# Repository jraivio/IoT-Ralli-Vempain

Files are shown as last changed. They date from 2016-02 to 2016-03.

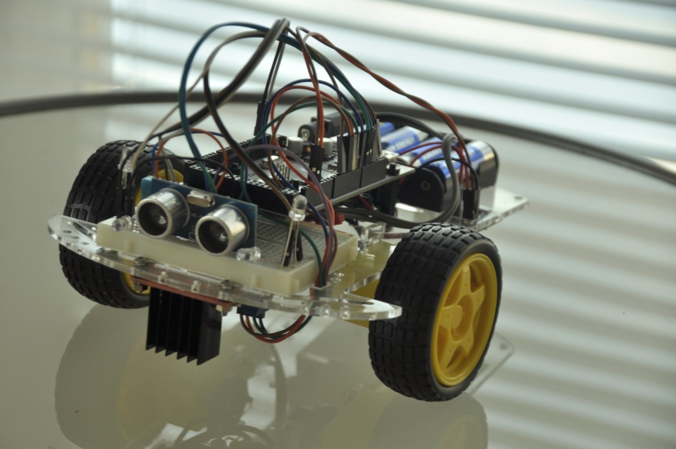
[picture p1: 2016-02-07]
Hardware/Pictures/_DSC5885.JPG

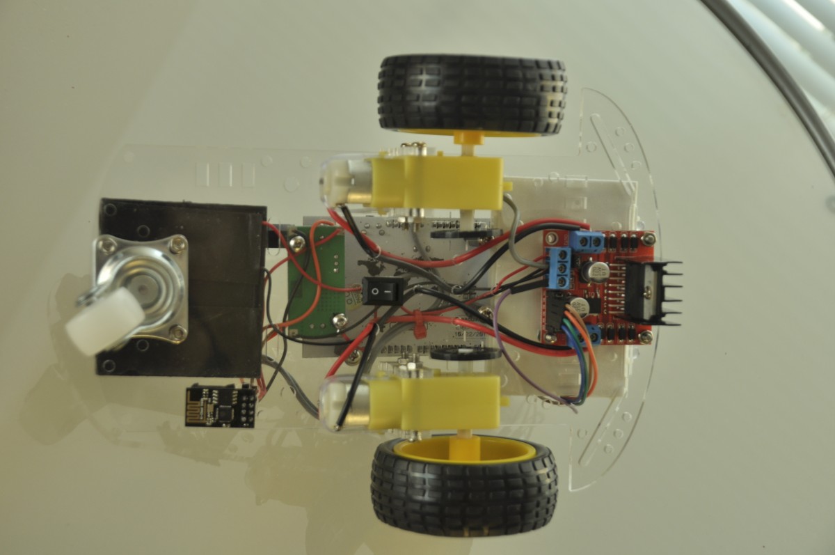
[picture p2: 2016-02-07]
Hardware/Pictures/_DSC5898.JPG

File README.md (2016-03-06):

# IoT-Ralli-Vempain
![alt tag] (https://github.com/jraivio/IoT-Ralli-Vempain/blob/master/Hardware/Pictures/Cloudyralli_mid.png) ![alt tag] (https://github.com/jraivio/IoT-Ralli-Vempain/blob/master/Hardware/Pictures/_DSC5885_small.JPG)

###Description of project:
This project aims to develop [Internet of Things (IoT)] (https://en.wikipedia.org/wiki/Internet_of_Things) specific development environment for educational institutions. Easy availability and low cost components are the design principles of this gadget. In addition, an important factor is the availability of the source code for hardware drivers. This project is focusing to produce a prototype device with required IoT features and interfaces. The brains to control a robot can be placed in the cloud server, if necessary.
Source code type of approach is mandatory. All used 3rd party libraries in this repository are also available from the github repositories as well. Including selected hardware e.g [Arduino] (https://www.arduino.cc) and [esp8266] (http://www.esp8266.com) both are based on the model of [open source electronics] (http://www.open-electronics.org/).  

###Content of Ralli-Vempain repository:     
- [Arduino Code - Refence functions to control the gadget] (https://github.com/jraivio/IoT-Ralli-Vempain/tree/master/ArduinoCode)    
- [Interface descriptions - Reference implementation to communicate with the gadget] (https://github.com/jraivio/IoT-Ralli-Vempain/wiki)  
- [Wiring and HW layouts - Instructions to install the gadget] (https://github.com/jraivio/IoT-Ralli-Vempain/tree/master/Hardware)  

###Getting started with development environment:        
- [Getting started with Arduino: Arduino development board pinouts, IDE setup, Arduino SW libraries, sample code, etc] (https://www.arduino.cc/en/Guide/HomePage)   
- [Getting started with esp8266: Basics, pinouts and flashing instruction, etc] (http://www.esp8266.com/wiki/doku.php?id=getting-started-with-the-esp8266)    
- [Open Electronics is the brainchild of a world leader in hobby electronics] (http://www.open-electronics.org)   
- [Arduino Course for Absolute Beginners] (https://www.youtube.com/watch?v=09zfRaLEasY)    
- [ESP8266 - Getting Started & Connected] (https://www.youtube.com/watch?v=z07zjfOHb8E)    
- [This project is using 3rd party libraries. The library bundle can be copied here to your local ...'Arduino/libraries' folder as such or alternatively you could download the latest versions from the original github location.] (https://github.com/jraivio/IoT-Ralli-Vempain/tree/master/ArduinoCode/libraries)

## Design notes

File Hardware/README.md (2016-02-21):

###Eye Candy: Ralli-Vempain droid equipped with all bells and whistles

![alt tag] (https://github.com/jraivio/IoT-Ralli-Vempain/blob/master/Hardware/Pictures/Ralli-Vempain-layout.jpg)

_Note that layout description is overal. Some late findings... 6V battery is not enough. 7V-12V is recommended._    
_Not up-to-dated picture. Large number of sensors are missing_     

###IOT Droid wiring diagram by Fritzing tool:
![alt tag] (https://github.com/jraivio/IoT-Ralli-Vempain/blob/master/Hardware/Pictures/Ralli-Vempain-Fritzing-wiring.png)
_Note that layout description is overal. L298N requires additional control pinouts. L298N enA-> Arduino pin8 and L298N enB-> Arduino pin3._    

Wiring diagram is designed by [Fritzing tool.](http://fritzing.org/home/) The source code of the above wiring diagram is available also in this [IOT-Ralli-Vempain repository](https://github.com/jraivio/IoT-Ralli-Vempain/blob/master/Hardware/Rally_Droid2.fzz)

###List of selected hardware:
- [Microcontroller: Arduino Mega2560] (https://www.arduino.cc/en/Main/ArduinoBoardMega2560)
- [H-Bridge motor driver: L298N] (http://www.geeetech.com/wiki/index.php/L298N_Motor_Driver_Board)
- [Distance sensor: HC-SR04] (http://www.electroschematics.com/8902/hc-sr04-datasheet/)
- [Temperature and Humidity sensor: DHT11] (http://www.micropik.com/PDF/dht11.pdf)
- [RFID reader/writer: Mifare 13.56Mhz RC522] (http://www.nxp.com/documents/data_sheet/MFRC522.pdf)
- [Infrared line track Sensor: TCRT5000] (http://www.aliexpress.com/item/Sensor-For-Arduino-LM393-IR-Infrared-Line-Tracking-Transducer-TCRT5000-Obstacle-Avoidance-Module-Board-Photoelectric-Switch/3259121781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)
- [IOT Wifi-serial bridge: ESP8266-01] (https://www.adafruit.com/images/product-files/2471/0A-ESP8266__Datasheet__EN_v4.3.pdf)
- [Frame, Wheels and DC motor] (http://www.aliexpress.com/item/New-Motor-Smart-Robot-Car-Chassis-Kit-Speed-Encoder-Battery-Box-For-Arduino-Free-Shipping/1924502066.html)
- [Battery 2 x 3.7V: 18650] (https://www.reddit.com/r/flashlight/wiki/18650)
- [400 Point Breadboard] (http://www.aliexpress.com/item/400-Tie-Point-Interlocking-Solderless-mini-Breadboard-Free-Shipping-Dropshipping/1248613686.html)
- [3.3v regulator: AMS1117] (http://www.aliexpress.com/item/1pc-DC-DC-AMS1117-1-2V-Step-Down-Voltage-Regulator-Adapter-Convertor-2P-Single-Row-Hot/32369895833.html)

###esp8266 - esp-link:    
![alt tag] (http://www.partco.biz/verkkokauppa/images/tuotekuvat/e/esp8266_esp-01_top-medium.jpg)

This demo setup is based on esp8266-01 Serial-Wifi bridge. The default AT based firmware of esp8266 has replaced by the esp-link version.

esp-link serial bridge description:    
https://github.com/jeelabs/esp-link#serial-bridge-and-connections-to-arduino-avr-arm-lpc-microcontrollers

esp-link firmware releases and flashing instructions for esp8266:     
https://github.com/jeelabs/esp-link#releases-downloads

###esp-link user interface:   
esp-link comes with very handy user interface. It is possible to configure and admistrate Wifi parameters, managing MQTT/REST parameters and also handling serial events from Arduino by the Web Browser. The UI allows to send and receive serial events. This feature makes life much easier in case of troubleshooting.    

esp-link web UI. example of μC Console:    
![alt tag] (https://github.com/jraivio/IoT-Ralli-Vempain/blob/master/Hardware/Pictures/esp-link.png)    

###esp8266-01 pinout:   
![alt tag] (http://www.partco.biz/verkkokauppa/images/tuotekuvat/e/esp8266_esp-01_pinout-large.jpg)

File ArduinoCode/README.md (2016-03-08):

###High level SW architecture:
![alt tag] (https://github.com/jraivio/IoT-Ralli-Vempain/blob/master/Hardware/Pictures/Ralli_Vempain_highlevel_SW_arc.png)

[Arduino sample code for Ralli-Vempain gadget] (https://github.com/jraivio/IoT-Ralli-Vempain/blob/master/ArduinoCode/Ralli_Vempain_arduinoMega2560.ino)

**Getting started with Arduino SW development environment:**    
- [Download IDE] (https://www.arduino.cc/en/Main/Software)    
- [Instructions] (https://www.arduino.cc/en/Guide/Environment)     

**Following 3rd party libraries in use:**   
- [Temperature & Humidity sensor DHT11, Adafruit version] (https://github.com/adafruit/DHT-sensor-library)     
- [JSON string parser, by Benoit Blanchon] (https://github.com/bblanchon/ArduinoJson)    
- [RFID Card reader MFRC522, by Miguel Balboa] (https://github.com/miguelbalboa/rfid)    
- [Ultrasonic HC-SR04 library for Arduino by J.Rodrigo] (https://github.com/JRodrigoTech/Ultrasonic-HC-SR04)    
- [RTC DS1307 library by Adafruit] (https://github.com/adafruit/RTClib)    
- [Gyroscope + accelerometer MPU-6050 library for Arduino by Jeff Rowberg] (https://github.com/jrowberg/i2cdevlib)

[The library bundle can be copied to your local ...'Arduino/libraries' folder as such or alternatively you could download the latest versions from the original github location.] (https://github.com/jraivio/IoT-Ralli-Vempain/tree/master/ArduinoCode/libraries)     

**Following functions in use:**  
- `JsonReportSensorDHT()`: // DHT11 sensor data reader function & json report creation    
- `JsonReportSensorRFID()`: // RFID card sensor reader function & json report creation    
- `JsonReportSensorEdge()`: // Edge sensor reader function & json report creation    
- `JsonReportSensorDistance()`: // Ultrasonic distance sensor reader function & json report creation    
- `JsonReportSensorAccAndGyro()` : // Gyroscope + accelerometer reader function & json report creation    
- `driveMotor()`:  // Motor control functions, adapted for L298N    
- `serialEvent1()`: // Monitoring new serial events from esp  
- `HandleIncommingJson()`: // json parser for incoming commands from esp    
- `setup()`: // Standard Arduino function to setup the system    
- `loop()`: // Standard Arduino loop function. Primary function to call other functions.   

_Note that details of json string formats are described in the [wiki part] (https://github.com/jraivio/IoT-Ralli-Vempain/wiki)_

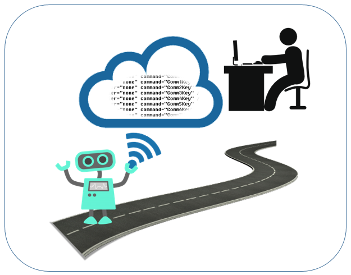
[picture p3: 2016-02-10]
Hardware/Pictures/Cloudyralli_mid.png

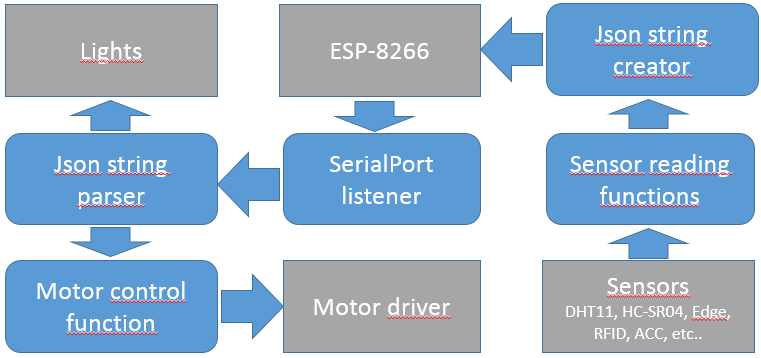
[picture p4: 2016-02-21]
Hardware/Pictures/Ralli_Vempain_highlevel_SW_arc.png

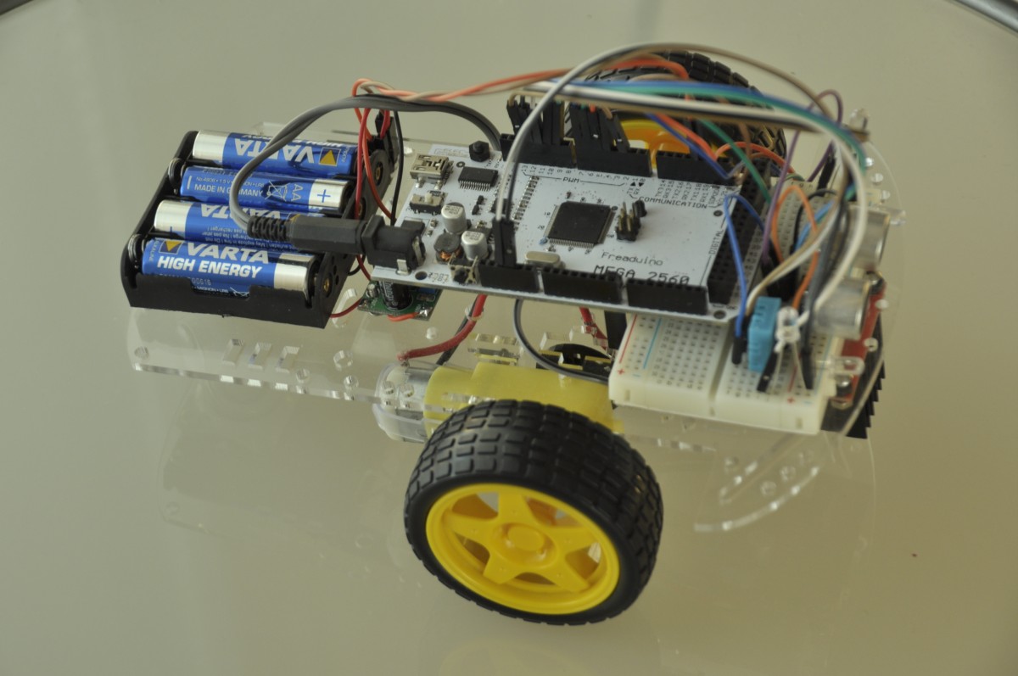
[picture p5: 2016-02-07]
Hardware/Pictures/_DSC5887.JPG

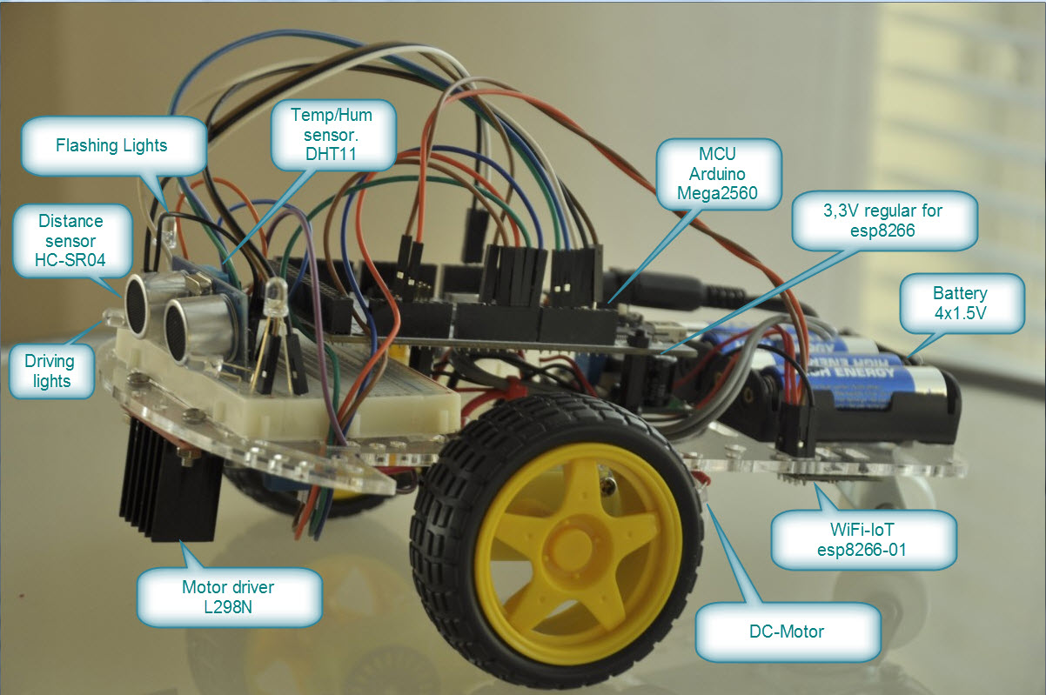
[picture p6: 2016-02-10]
Hardware/Pictures/Ralli-Vempain-layout.jpg

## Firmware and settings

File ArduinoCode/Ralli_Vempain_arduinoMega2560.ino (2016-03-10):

// IOT RalliDroid  
// Copyright Jukka Raivio and Jussi Salonen 2016
// MIT License
// 
// Example code is based on Arduino Mega2560 
//
// This arduino demo setup is connected to esp8266 Wifi via serial. 
// The http services are managed by esp-link firmware in ESP. The esp unit is working as Wifi-Serial bridge.
// No code changes are required for the esp-link
// Github repository for esp-link https://github.com/jeelabs/esp-link

// Temperature & Humidity sensor DHT11 lib & setup
// Adafruit version, https://github.com/adafruit/DHT-sensor-library
// Json description: https://github.com/jraivio/IoT-Ralli-Vempain/wiki
#include "DHT.h"
#define DHTPIN  2       // 2 digital pin 
#define DHTTYPE DHT11   
DHT dht(DHTPIN, DHTTYPE);

// I2C library
#include <Wire.h>
// RTC library by adafruit https://github.com/adafruit/RTClib
#include "RTClib.h"
RTC_DS1307 RTC;
String TimeStr ="";

// Multitasking functions by Arduino millis
// Initialization to enable multithreading features by using millis() functions  
// Sensor update interval
unsigned long previousMillis = 0;       // will store last time sensor updated
// the follow variables is a long because the time, measured in miliseconds,
// will quickly become a bigger number than can be stored in an int.
const long interval = 10000;            // Sensor data sending interval

// Json parser lib Copyright Benoit Blanchon 2014-2016, MIT License
// https://github.com/bblanchon/ArduinoJson
// Json description: https://github.com/jraivio/IoT-Ralli-Vempain/wiki
#include <ArduinoJson.h>
const char* command;
// Serial data handling, global variables
String inputString = "";         // a string to hold incoming data
boolean stringComplete = false;  // whether the string is complete
char inChar; // a char to handle incoming data

// RFID tag reader (NFC) MFRC522
/* ------------------------------------
  * RFID Card reader MFRC522 library by Miguel Balboa https://github.com/miguelbalboa/rfid
  * Signal      MFRC522      Mega 2560
  *             Pin          Pin       ´
  * -------------------------------------
  * RST/Reset   RST          49         
  * SPI SS      SDA(SS)      53       
  * SPI MOSI    MOSI         51        
  * SPI MISO    MISO         50        
  * SPI SCK     SCK          52        
*/
#include <SPI.h> // Arduino default SPI library
#include <MFRC522.h> 
#define RST_PIN   49     // Configurable, see typical pin layout above (valk)
#define SS_PIN    53    // Configurable, see typical pin layout above (vihr)
MFRC522 rfid(SS_PIN, RST_PIN); // Instance of the class
MFRC522::MIFARE_Key key; 
// Init array that will store new NUID 
byte nuidPICC[3];

/*
 * Gyroscope + accelerometer MPU-6050 library for Arduino by Jeff Rowberg
 * https://github.com/jrowberg/i2cdevlib
 * 
 */
#include <I2Cdev.h>
#include <MPU6050.h>

// Arduino Wire library is required if I2Cdev I2CDEV_ARDUINO_WIRE implementation
// is used in I2Cdev.h
#if I2CDEV_IMPLEMENTATION == I2CDEV_ARDUINO_WIRE
    #include "Wire.h"
#endif

// We use I2C address 0x69 as the default (0x68) is used by RTC
// Due to this AD0 pin must be pulled high
MPU6050 accelgyro(0x69);

// Global variables to store the values
int16_t ax, ay, az;
int16_t gx, gy, gz;

// Ultrasonic HC-SR04 library for Arduino by J.Rodrigo https://github.com/JRodrigoTech/Ultrasonic-HC-SR04
// Json description: https://github.com/jraivio/IoT-Ralli-Vempain/wiki
// Max distance 51 cm
#include <Ultrasonic.h>
#define TRIG_PIN 10     // Configurable Arduino pins for HC-SR04 Trig PIN
#define ECHO_PIN 9  // Configurable Arduino pins for HC-SR04 Echo pins
Ultrasonic ultrasonic(TRIG_PIN,ECHO_PIN); 

// Edge sensor pinouts
#define right_edge 23 // Right sensor
#define left_edge 22 // Left sensor

// Motor driver Setup
// Pins L298N -> Mega board
int enA = 8;
int in1 = 4;
int in2 = 5;
int in3 = 6;
int in4 = 7;
int enB = 3;
boolean motor_active = false;
// for motor delay
unsigned long mStartMillis = 0;      // will store last time motor delay update
int course; // direction
int mspeed; // motor speed
int mdelay; // motor delay
// millis for sensor reading interval while moving, delay 500 ms
boolean sensor_moving = false;
int sensor_moving_reports = 500;
unsigned long sensor_moving_previousMillis = 0;      // will store last time light delay update
// light blinking 
boolean pin13_blinking = false;
boolean pin12_blinking = false;
boolean pin11_blinking = false;
int pin13_delay;
int pin12_delay;
int pin11_delay;
unsigned long pin13_previousMillis = 0;      // will store last time light delay update
unsigned long pin12_previousMillis = 0;      // will store last time light delay update
unsigned long pin11_previousMillis = 0;      // will store last time light delay update

void JsonReportSensorDHT() {
 
  // DHT functions
  // Reading temperature or humidity takes about 250 milliseconds!
  float h = dht.readHumidity();  float t = dht.readTemperature();
  // Read temperature as Fahrenheit (isFahrenheit = true)
    float f = dht.readTemperature(true);
    // Compute heat index in Fahrenheit (the default)
    float hif = dht.computeHeatIndex(f, h);
    // Compute heat index in Celsius (isFahreheit = false)
    float hic = dht.computeHeatIndex(t, h, false);
    // Check if any reads failed and exit early (to try again).
    if (isnan(h) || isnan(t) || isnan(f)) {
        // Debugging
        //Serial.println("Failed to read from DHT sensor!");
        return;
    }
    // Create Json for sensor print out
    StaticJsonBuffer<512> jsonOutBuffer;   // 514 B
    String rootJson = ""; String arrayJson = "";
    JsonObject& root = jsonOutBuffer.createObject();
    root["sensor"] = "temp_hum"; root["time"] =  TimeStr; JsonArray& array = jsonOutBuffer.createArray();
    array.add(t); array.add(h);
    // Print to Serial
    root.printTo(rootJson); array.printTo(arrayJson); String JointJson = rootJson + ":" + arrayJson + "}";
    Serial1.println(JointJson);
    return;
}

void JsonReportSensorDistance(){

  StaticJsonBuffer<512> jsonOutBuffer;   // 514 B
  String rootJson = ""; String arrayJson = "";
  JsonObject& root = jsonOutBuffer.createObject();
  root["sensor"] = "distance"; root["time"] =  TimeStr; JsonArray& array = jsonOutBuffer.createArray();
  array.add(ultrasonic.Ranging(CM)); // CM or INC
    // Debugging
    //Serial.print(ultrasonic.Ranging(CM)); // CM or INC
    //Serial.println(" cm" ); 
  root.printTo(rootJson); array.printTo(arrayJson); String JointJson = rootJson + ":" + arrayJson + "}";
    // Debugging
    //Serial.println("json string for edge:" + JointJson);
  Serial1.println(JointJson);
  return;
}  
/*
 *   Read accelerometer and gyroscope raw values and send them
 *   to ESP
 * 
 */
void JsonReportSensorAccAndGyro(){
  // read raw accel/gyro measurements from device
  accelgyro.getMotion6(&ax, &ay, &az, &gx, &gy, &gz);

  // Construct json
  StaticJsonBuffer<512> jsonOutBuffer;   // 514 B
  String rootJson = ""; 
  String arrayJson = "";
  JsonObject& root = jsonOutBuffer.createObject();
  
  root["sensor"] = "acc_gyro"; 
  root["time"] =  TimeStr;
  JsonArray& array = jsonOutBuffer.createArray();
  array.add( ax );
  array.add( ay );
  array.add( az );
  array.add( gx );
  array.add( gy );
  array.add( gz );
  
  root.printTo(rootJson); 
  array.printTo(arrayJson); 
  String JointJson = rootJson + ":" + arrayJson + "}";
  // Debuggung
  //Serial.println("json string for edge:" + JointJson);
  Serial1.println(JointJson); // Sending to ESP
}

void JsonReportSensorEdge() {
   StaticJsonBuffer<512> jsonOutBuffer;   // 514 B
  String rootJson = ""; String arrayJson = "";
  JsonObject& root = jsonOutBuffer.createObject();
  root["sensor"] = "edge"; 
  root["time"] =  TimeStr;
  JsonArray& array = jsonOutBuffer.createArray();
  array.add( digitalRead(left_edge) );
  array.add( digitalRead(right_edge) );
  
  root.printTo(rootJson); array.printTo(arrayJson); String JointJson = rootJson + ":" + arrayJson + "}";
  // Debuggung
  //Serial.println("json string for edge:" + JointJson);
  Serial1.println(JointJson);
  return;
}  
void JsonReportSensorRFID() {
  if ( ! rfid.PICC_ReadCardSerial()) 
    return;
  Serial.print(F("PICC type: "));
  MFRC522::PICC_Type piccType = rfid.PICC_GetType(rfid.uid.sak);
  Serial.println(rfid.PICC_GetTypeName(piccType));
  // Check is the PICC of Classic MIFARE type
  if (piccType != MFRC522::PICC_TYPE_MIFARE_MINI &&  
    piccType != MFRC522::PICC_TYPE_MIFARE_1K &&
    piccType != MFRC522::PICC_TYPE_MIFARE_4K) {
    Serial.println(F("Your tag is not of type MIFARE Classic."));
    return;
  }
  if (rfid.uid.uidByte[0] != nuidPICC[0] || 
    rfid.uid.uidByte[1] != nuidPICC[1] || 
    rfid.uid.uidByte[2] != nuidPICC[2] || 
    rfid.uid.uidByte[3] != nuidPICC[3] ) {
    Serial.println(F("A new card has been detected."));
    // Define Json for sensor print out
    StaticJsonBuffer<512> jsonOutBuffer;   // 514 B
    String rootJson = "";
    String arrayJson = "";
    JsonObject& root = jsonOutBuffer.createObject();
    root["sensor"] = "rfid";
    JsonArray& array = jsonOutBuffer.createArray();
    // Store NUID into nuidPICC array
    for (byte i = 0; i < 4; i++) {
      nuidPICC[i] = rfid.uid.uidByte[i];
      }   
    //Serial.println(F("The NUID tag is:"));
    //Serial.print(F("In dec: "));
    byte *buffer = rfid.uid.uidByte; 
    byte bufferSize = rfid.uid.size;
    String NUID = "";
    for (byte i = 0; i < bufferSize; i++) {
      //Serial.print(buffer[i] < 0x10 ? " 0" : " ");
      //Serial.print(buffer[i], DEC);
      NUID = String(NUID + String(buffer[i], DEC)); 
      }
    array.add(NUID);
    // Print json string to Serial1
    root.printTo(rootJson);
    array.printTo(arrayJson);
    String JointJson = rootJson + ":" + arrayJson + "}";
    //Serial.println("json string for rfid:" + JointJson);
    Serial1.println(JointJson);
    }
  else Serial.println(F("Card read previously."));
  rfid.PICC_HaltA(); // Halt PICC
  rfid.PCD_StopCrypto1(); // Stop encryption on PCD
  return;  
}

void driveMotors()
{
    // this function will run the motors across the range of possible speeds
    // note that maximum speed is determined by the motor itself and the operating voltage
    // the PWM values sent by analogWrite() are fractions of the maximum speed possible by your hardware
      // Drive Forward  
      if (course == 1) {
        digitalWrite(in1, HIGH); digitalWrite(in2, LOW); digitalWrite(in3, HIGH); digitalWrite(in4, LOW); 
        analogWrite(enA, mspeed); analogWrite(enB, mspeed);
      }
      // Drive Backward
      else if (course == 2 ) {
        digitalWrite(in1, LOW); digitalWrite(in2, HIGH); digitalWrite(in3, LOW); digitalWrite(in4, HIGH); 
        analogWrite(enA, mspeed); analogWrite(enB, mspeed);
      }
      // Turn Right, direction forward
      else if (course == 3 ) {
        digitalWrite(in1, LOW); digitalWrite(in2, LOW); digitalWrite(in3, HIGH); digitalWrite(in4, LOW); 
        analogWrite(enA, mspeed); analogWrite(enB, mspeed);
      }
      // Turn Left, direction forward
      else if (course == 4 ) {
        digitalWrite(in1, HIGH); digitalWrite(in2, LOW); digitalWrite(in3, LOW); digitalWrite(in4, LOW); 
        analogWrite(enA, mspeed); analogWrite(enB, mspeed);
      }
      // Stop
      else if (course == 0) {
        // now turn off motors
        digitalWrite(in1, LOW); digitalWrite(in2, LOW); digitalWrite(in3, LOW); digitalWrite(in4, LOW);  
      }  
}

void stopMotors() {
      // now turn off motors
    // clean up & return
    digitalWrite(in1, LOW); digitalWrite(in2, LOW); digitalWrite(in3, LOW); digitalWrite(in4, LOW);
    course = NULL;
    mspeed = NULL;
    mdelay = NULL;
    motor_active = false;
    // return;
}
/*
  SerialEvent occurs whenever a new data comes in the
 hardware serial RX.  This routine is run between each
 time loop() runs, so using delay inside loop can delay
 response.  Multiple bytes of data may be available.
 */
void serialEvent1() {
  while (Serial1.available()> 0) {
    inChar = (char)Serial1.read(); // get the new byte: 
    inputString += inChar; // add it to the inputString:
    // if the incoming character is a newline, set a flag
    // so the main loop can do something about it:
    if (inChar == '\n') {
        stringComplete = true;
    }
  }
}
void HandleIncomingJson() {
    StaticJsonBuffer<512> jsonInBuffer;                 
    const char *JsonChar = inputString.c_str(); // 1 KB
    JsonObject& root = jsonInBuffer.parseObject(JsonChar);
    int pin;
    int value;
    int ldelay;
    
    // Verify Json 
    if (JsonChar!=NULL && !root.success()) {
      Serial.println("parseObject() failed: ");
      Serial.println(JsonChar);
    }
    else {
        // Led pins 13-11
        command = root["command"];
        pin = root["data"][0];
        value = root["data"][1];
        ldelay = root["data"][2];
        course = root["mdata"][0];
        mspeed = root["mdata"][1];
        mdelay = root["mdata"][2];
    if (command="lights") {
    // Lights on, not blinking
      if (value == 1 && (ldelay == 0 || ldelay == NULL)){
        digitalWrite(pin, HIGH);
        if (pin == 13) { pin13_blinking = false; }
        if (pin == 12) { pin12_blinking = false; }   
        if (pin == 11) { pin11_blinking = false; }                
      }
      // blinking lights
        else if (value == 1 && (!ldelay == 0 || !ldelay == NULL)){
          if (pin == 13) { pin13_blinking = true; pin13_delay = ldelay;}
          if (pin == 12) { pin12_blinking = true; pin12_delay = ldelay;}   
          if (pin == 11) { pin11_blinking = true; pin11_delay = ldelay;}              
        }
        // Lights off
        else if (value == 0 ){
          digitalWrite(pin, LOW);
          if (pin == 13) { pin13_blinking = false; }
            if (pin == 12) { pin12_blinking = false; }   
            if (pin == 11) { pin11_blinking = false; }  
          }
        }
    if (command ="drive") {motor_active = true; mStartMillis = millis();}
    }
  // returning the default state of serialEvent1()
  stringComplete = false;
  // clean json incoming data buffers
  pin = NULL; value = NULL; ldelay = NULL;
  inputString="";
  inChar = NULL; JsonChar = NULL;
  return;      
}

void readTime() {

    DateTime now = RTC.now();
    String Year = String(now.year(), DEC);
    String Month = String(now.month(), DEC);
    String Day = String(now.day(), DEC);
    String Hour = String(now.hour(), DEC);
    String Minutes = String(now.minute(), DEC);
    String Seconds = String(now.second(), DEC);
    TimeStr = Year + "/" + Month + "/" + Day + ":" + Hour + ":" + Minutes + ":" + Seconds;
    // Debugging
    // Serial.print(TimeStr);
    // Serial.println();
}

void setup() {
    // initialize both serial ports:
    Serial.begin(9600); // Debugging
    delay(1000);
    Serial1.begin(115200); // Serial for esp8266
    delay(1000);
    Wire.begin(); // start I2C & RTC
    RTC.begin();
    if (! RTC.isrunning()) {
      Serial.println("RTC is NOT running!");
      // following line sets the RTC to the date & time this sketch was compiled
      //RTC.adjust(DateTime(__DATE__, __TIME__));
    }
    // initialize digital pin 13-11 as an output (for LEDs)
    pinMode(13, OUTPUT); // Main lights leds
    pinMode(12, OUTPUT); // Direction lights
    pinMode(11, OUTPUT);
    // Egde sensor input pins
    pinMode(right_edge,INPUT); // Right sensor
    pinMode(left_edge,INPUT); // Left sensor
    inputString.reserve(256); // reserve 256 bytes for the inputString:
    dht.begin(); // Init DHT
    accelgyro.initialize(); //  ACC & Gyro initialization 
    // RFID setup
    SPI.begin(); // Init SPI bus
    rfid.PCD_Init(); // Init MFRC522 
    for (byte i = 0; i < 6; i++) { key.keyByte[i] = 0xFF; } // RFID byte handling
    // HC-SR04 distance sensor setup (TBD, currently fixed VCC/GND)
    //pinMode(4, OUTPUT); // VCC pin
    //pinMode(7, OUTPUT); // GND ping
    //digitalWrite(4, HIGH); // VCC +5V mode  
    //digitalWrite(7, LOW);  // GND mode
}
void loop() {
    // update interval
    unsigned long currentMillis = millis();
    // DHT Sensor reporting
    if (currentMillis - previousMillis >= interval) {
      // save the last time of sensor reporting
      readTime();
      previousMillis = currentMillis;    
      JsonReportSensorDHT();
      if (motor_active == false) {
       JsonReportSensorDistance(); 
       JsonReportSensorEdge();
       JsonReportSensorAccAndGyro();
      } // slow down reporting frequency in static cases
    }
    if (motor_active == true) { // speed up reporting frequency in case of moving
      currentMillis = millis();
      if (currentMillis - mStartMillis >= sensor_moving_reports ) {
        readTime();
        JsonReportSensorDistance();
        JsonReportSensorEdge();
        JsonReportSensorAccAndGyro();
      }
    }
    // Look for new RFID cards
    if ( rfid.PICC_IsNewCardPresent()) { JsonReportSensorRFID(); }
    // Handling incoming Json from serial port 
    // JSon serial read, print the string when a newline arrives:
    serialEvent1(); if (stringComplete == true) { HandleIncomingJson();}
    
    // Light blinking
    if ( pin13_blinking == true){
      currentMillis = millis();
      if ( currentMillis - pin13_previousMillis >= pin13_delay ) {
          pin13_previousMillis = currentMillis; 
          if (digitalRead(13) == LOW) { digitalWrite(13, HIGH);
          } else { digitalWrite(13, LOW); }
        }
    }                       
    if ( pin12_blinking == true){
      currentMillis = millis();
      if (currentMillis - pin12_previousMillis >= pin12_delay) {
        pin12_previousMillis = currentMillis; 
        if (digitalRead(12) == LOW) { 
          digitalWrite(12, HIGH);
        } else { 
          digitalWrite(12, LOW); }
        }             
    }
    if ( pin11_blinking == true){
      currentMillis = millis();
      if ( currentMillis - pin11_previousMillis >= pin11_delay) {
        pin11_previousMillis = currentMillis; 
        if (digitalRead(11) == LOW) { 
          digitalWrite(11, HIGH);
        } else { 
          digitalWrite(11, LOW); }
        }             
    }     
    // Drive motors
    if (motor_active == true ) {
       currentMillis = millis();
       driveMotors();
       if (currentMillis - mStartMillis >= mdelay) {       
        stopMotors(); }           
    }  
 }

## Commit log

2016-01-25 Create Ralli_vempain_arduinoMega2560
    First version
    Working:
    - json parser
    - leds ok
    - motors working ... somehow ;-)
    Todo:
    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
2016-02-05 Update Ralli_Vempain_arduinoMega2560.ino
    L298N driver replaced
    [Ralli_Vempain_arduinoMega2560.ino]
2016-02-06 Sources of Fritzing wiring diagram
    [Rally_Droid2.fzz]
2016-02-06 Structure changes ArduinoCode folder created
2016-02-06 New folder ArduinoCode
2016-02-06 Update Ralli_Vempain_arduinoMega2560.ino
    Functioning pretty well now ;-)
    Changes:Structure changes due to millis()
    New: led blinking
    TODO: Still motor function interrupts the other functions
2016-02-07 New picture files
    [Rally_Droid2.fzz]
2016-02-20 Update Ralli_Vempain_arduinoMega2560.ino
    Edge sensor included
2016-02-21 Update README.md
    Ultrasonic HC-SR04 library for Arduino included
2016-02-21 Update README.md
    Ultrasonic HC-SR04 library and edge sensor functions for Arduino are included
2016-02-21 Update Ralli_Vempain_arduinoMega2560.ino
    Sensors DHT, Edge, RFID and Distance are working, Todo motor function interrupts all other functions
2016-02-21 Arc updated with new sensors
2016-02-21 updated wiring
2016-03-02 Update Ralli_Vempain_arduinoMega2560.ino
    multitasking (millis) specitic refactoring by jsalonen
2016-03-06 Update Ralli_Vempain_arduinoMega2560.ino
    RTC DS1307 and time support for sensors included
2016-03-06 new: - Arduino library bundle - RTC included to wiring diagram
2016-03-06 Modified RTC wiring
2016-03-06 RTC updated for wiring
    [Rally_Droid2.fzz]
2016-03-08 Accelerometer + gyroscope reporting added
2016-03-08 Update Ralli_Vempain_arduinoMega2560.ino
    right edge pin to 23
2016-03-10 Update libraries, including compass and etc I2C related
2016-03-10 USB drivers included
